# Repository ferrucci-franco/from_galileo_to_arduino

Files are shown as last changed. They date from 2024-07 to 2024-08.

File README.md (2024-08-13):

# From Galileo Galilei to Arduino
This page presents a low-budget (under USD 100) didactic tool for a simple pendulum with angle measurement and real-time plotting. 

The project involves measuring the angle of a pendulum and plotting the data in real-time using a incremental encoder, an Arduino UNO board and a computer running a graphical user interface, programmed in Python.

This tool, designed by [Franco FERRUCCI](mailto:franco.ferrucci@upf.pf) is part of the 'Introduction to Practical Work' sessions in the first year of the 'Engineering Science' bachelor's program at the University of French Polynesia.

You will find here all the necessary information to replicate this piece of equipment, such as the bill of material, the 3D models (for 3D printing), the code running in the Arduino board and the Python program that runs on the computer.

<p align="center">
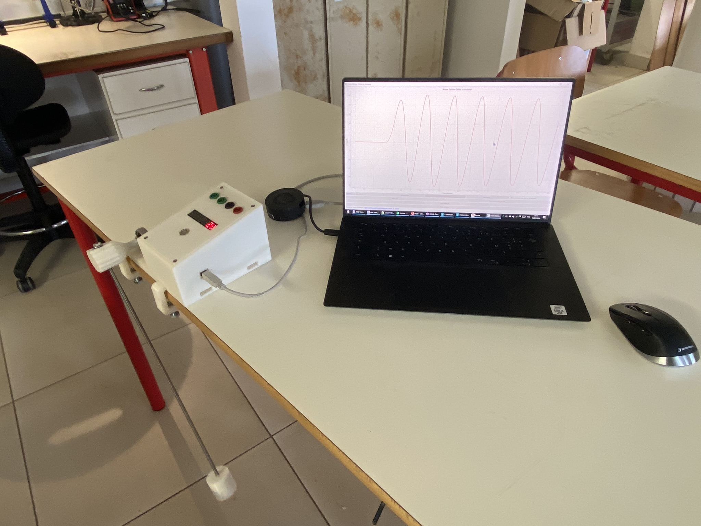
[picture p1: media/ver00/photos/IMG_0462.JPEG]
Intoductory photo
  
</p>

### How does it work?
The Arduino board reads signals from the incremental encoder, computes the pendulum angle, and displays it on a physical display. Simultaneously, it sends the data via a serial interface to a computer. A tool on the computer runs Python code that plots the pendulum angle in real time and allows the user to save the data to disk as a CSV file.

## Table of Contents
- [Repository recap](#repository-recap)
- [Videos](#videos)
- [Photos & Screenshots](#photos--screenshots)
  - [Photos](#photos)
  - [Real-Time Plot](#real-time-plot)
  - [Exported CSV file visualisation](#exported-csv-file-visualisation)
  - [Curve fitting](#curve-fitting)
- [Requirements](#requirements)
- [Python Code Installation](#python-code-installation)
- [Contribution](#contribution)
- [Contact](#contact)

## Repository recap
In this repository you will find the following elements:
- Arduino code
- Python code for:
  - The real-time graphical user interface (GUI)
  - An off-line data visualization tool of CSV measured data (using Plotly library).
  - A script with a curve-fitting tool for a sinusoidal curve with exponential decay.
  - A script with the numerical integration of the equations of motion of a physical pendulum and comparison with measurement (with an example!).
- CAD files and 3D printer files (I used Creality K1 printer). In a future commit I will upload the Fusion360 files.
- Pictures and screenshots.
- Bill of material (comming soon).
- Electrical diagram (comming soon).
## Videos
For an overview and demonstration of the project, you can watch the following videos:
- [Video 1 (YouTube)](https://youtu.be/FJ6ZPmrugeg?si=X3V44YTVULSpro3k)
- [Video 2 (YouTube)](https://youtube.com/shorts/YBjDby0IXsI?si=bWYj2W4k94o8iF31)
## Photos & Screenshots
Here are some photos and screenshots of the project in action:

### Photos
<p align="center">
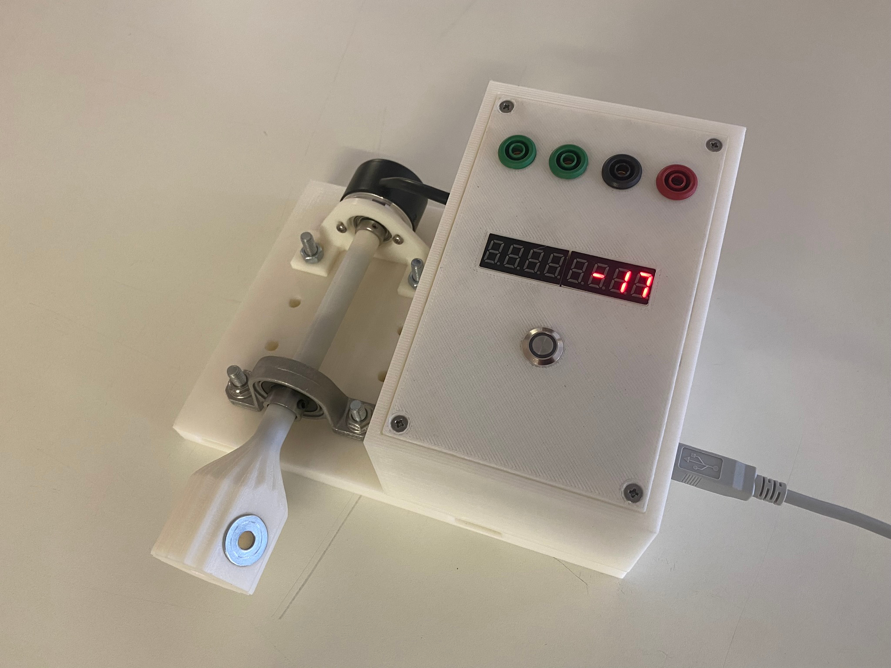
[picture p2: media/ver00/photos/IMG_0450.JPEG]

</p>
<p align="center">
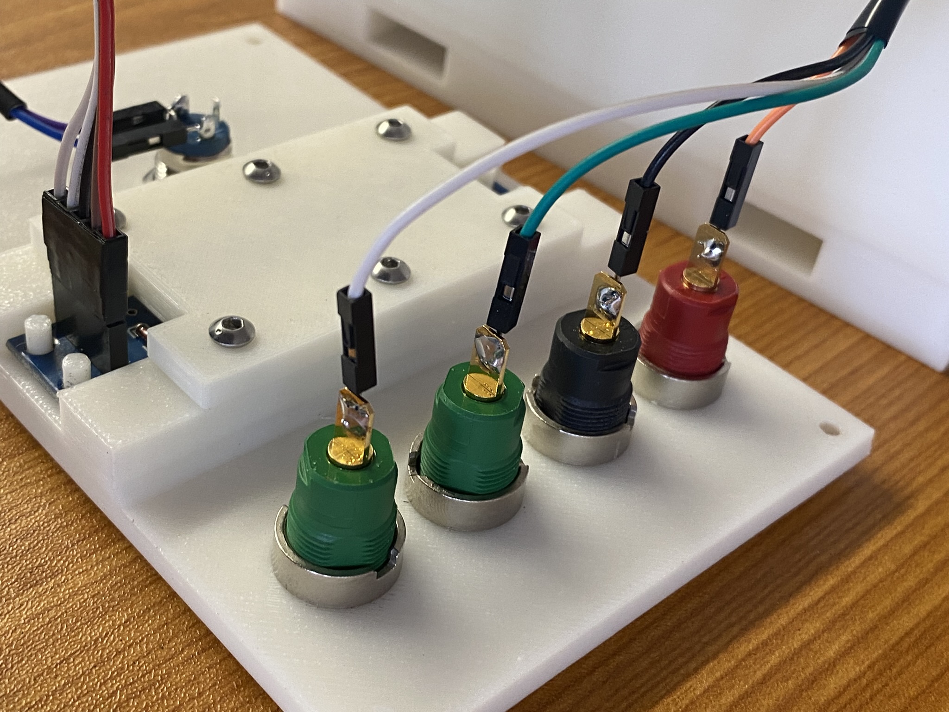
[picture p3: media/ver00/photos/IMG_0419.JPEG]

</p>
<p align="center">
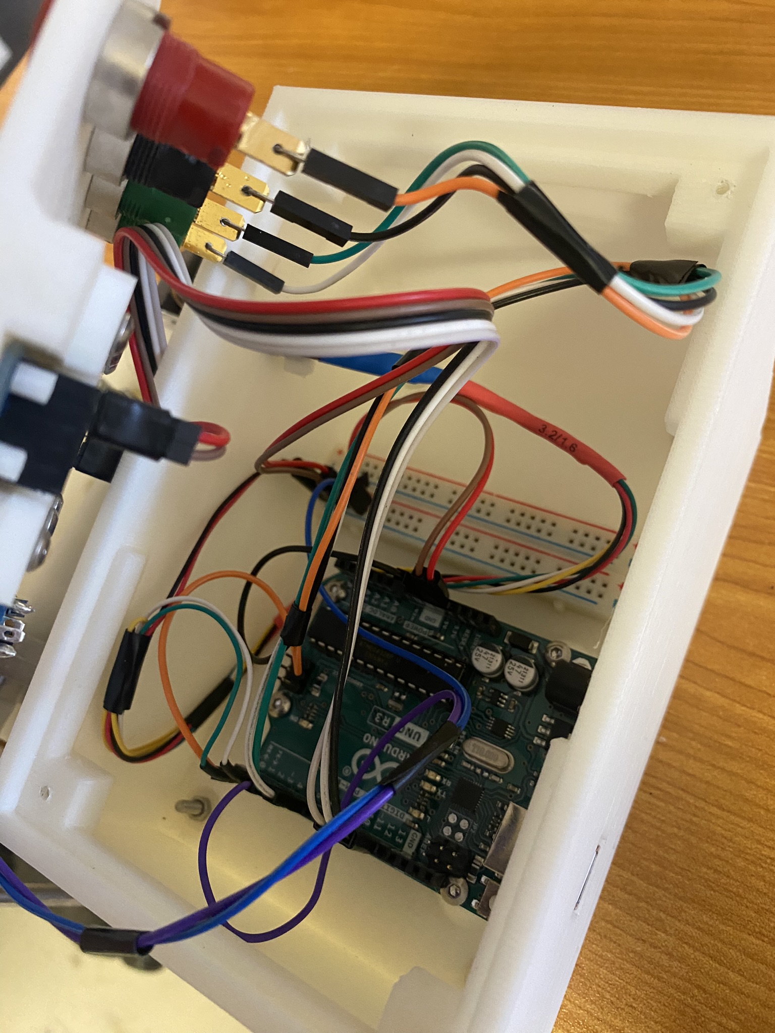
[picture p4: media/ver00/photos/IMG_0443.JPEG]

</p>

### Real-Time Plot
<p align="center">
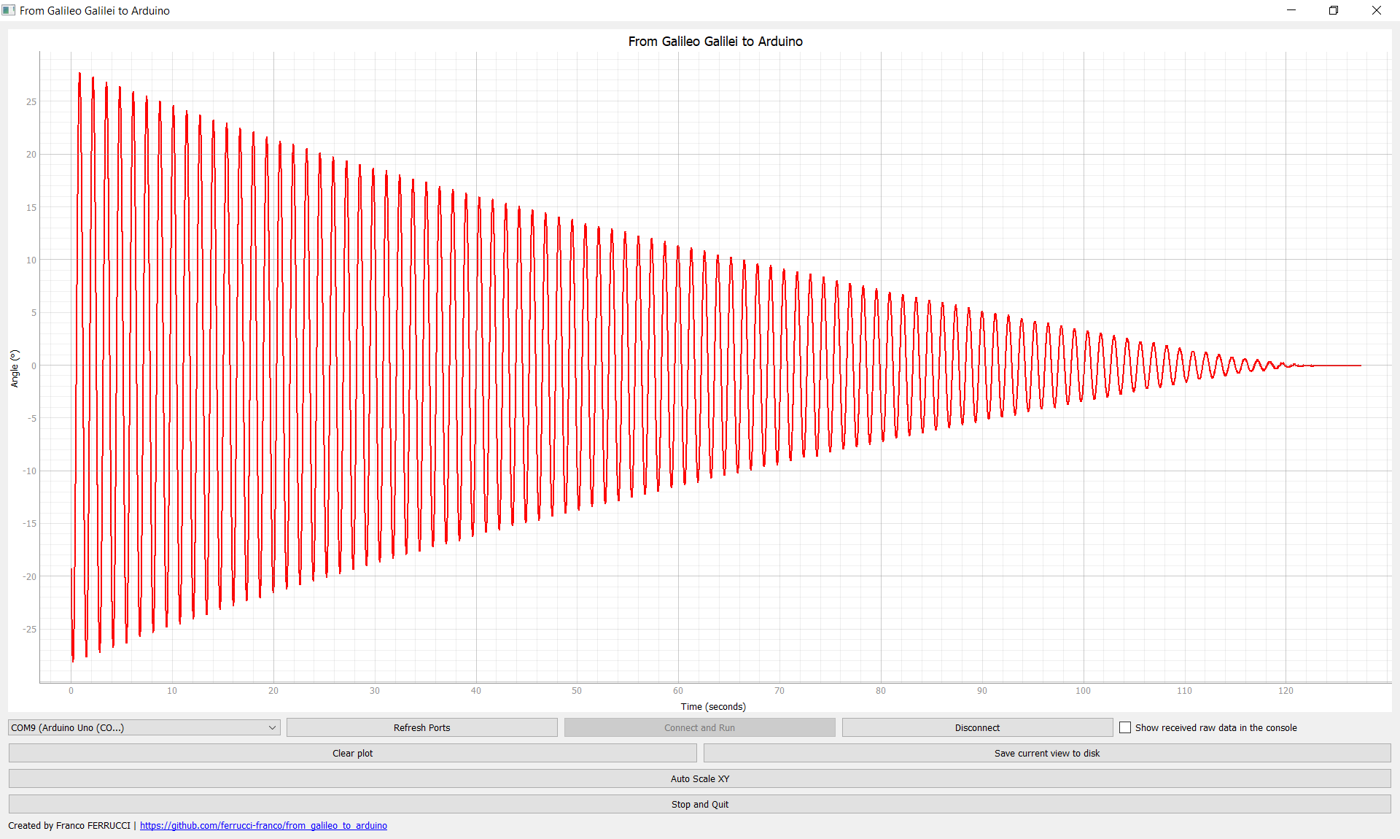
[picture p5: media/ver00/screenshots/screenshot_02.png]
Real-Time Plot

</p>

### Exported CSV file visualisation
<p align="center">
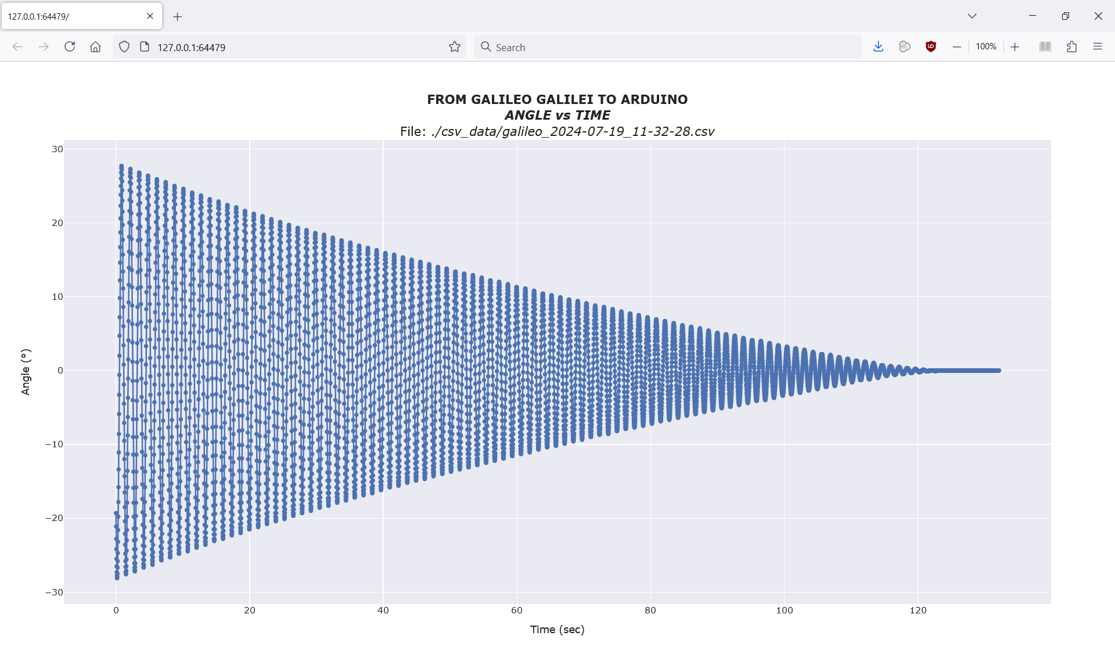
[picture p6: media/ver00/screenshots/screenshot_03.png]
Data Acquisition

</p>

### Curve fitting
<p align="center">
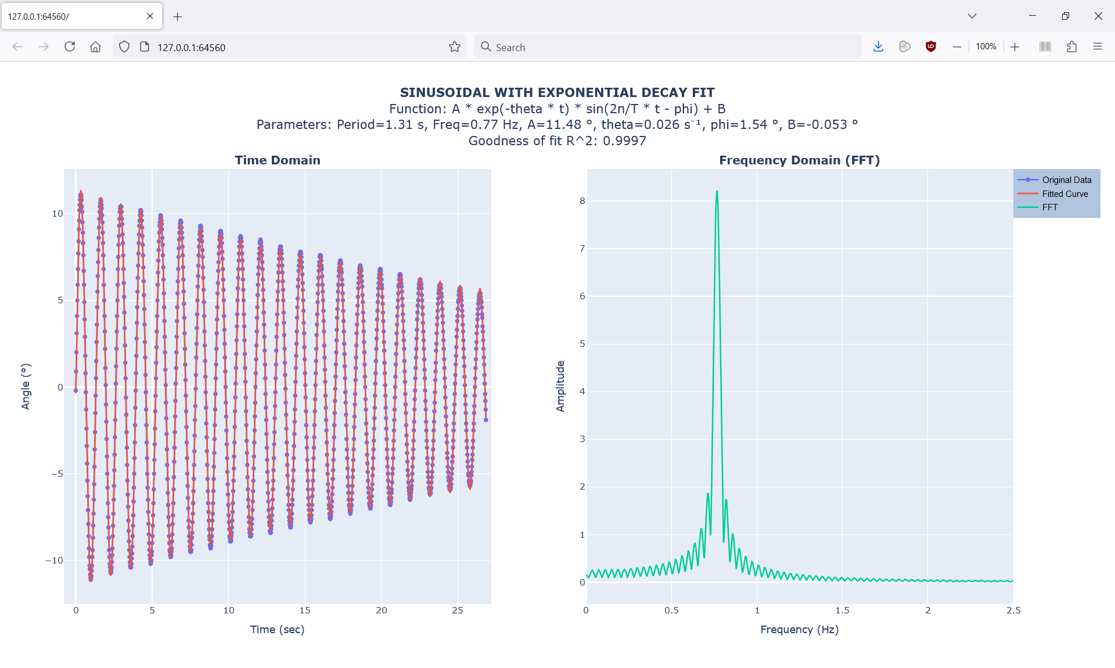
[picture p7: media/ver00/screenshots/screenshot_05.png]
Example Data Plot

</p>

## Requirements
- Arduino or compatible microcontroller
- Python 3.x
- Required Python libraries: `PyQt5`, `pyqtgraph`, `serial`, `pandas`, `plotly`

## Python Code Installation
To set up the necessary environment for running the provided Python code, follow the instructions below. This guide will walk you through creating an Anaconda environment called `galileo_to_arduino` and installing all the required libraries.
### Step 1: Install Anaconda
If you do not have Anaconda installed, you can download and install it from [the official Anaconda website](https://www.anaconda.com/products/distribution). If you don't have that much room in you hard drive, try Miniconda instead [(see link here)](https://docs.anaconda.com/miniconda/)
### Step 2: Create a New Environment
Open the Anaconda prompt and execute the following commands to create a new environment called `galileo_to_arduino`:
```
conda create --name galileo_to_arduino
```
### Step 3: Activate the Environment
Activate the newly created environment with the following command:
```
conda activate galileo_to_arduino
```
### Step 4: Install Required Libraries
Install the necessary libraries using the following commands:
```
conda install pyqt
conda install -c conda-forge pyqtgraph
conda install -c conda-forge pyserial
conda install pandas
conda install numpy
conda install scipy
conda install -c plotly plotly
```
### Step 5: Verify the Installation
To ensure all the libraries are installed correctly, you can run the following Python code:
```
import sys
import re
import os
from PyQt5.QtWidgets import QApplication, QMainWindow, QVBoxLayout, QHBoxLayout, QWidget, QPushButton, QComboBox, QCheckBox, QLabel
from PyQt5.QtCore import QTimer, QThread, pyqtSignal
import pyqtgraph as pg
import serial
import serial.tools.list_ports
import datetime
import pandas as pd
import numpy as np
from scipy.integrate import solve_ivp
import plotly.graph_objs as go
import plotly.io as pio
from scipy.optimize import curve_fit
import scipy.fftpack
from plotly.subplots import make_subplots
```
If no errors occur, the environment is set up correctly.
## Contribution
Feel free to contribute to this project by providing feedback, bug reports, or enhancements. You can also fork the repository and submit a pull request.
## Contact
For any questions or further information, please contact [Franco FERRUCCI](mailto:franco.ferrucci@upf.pf).

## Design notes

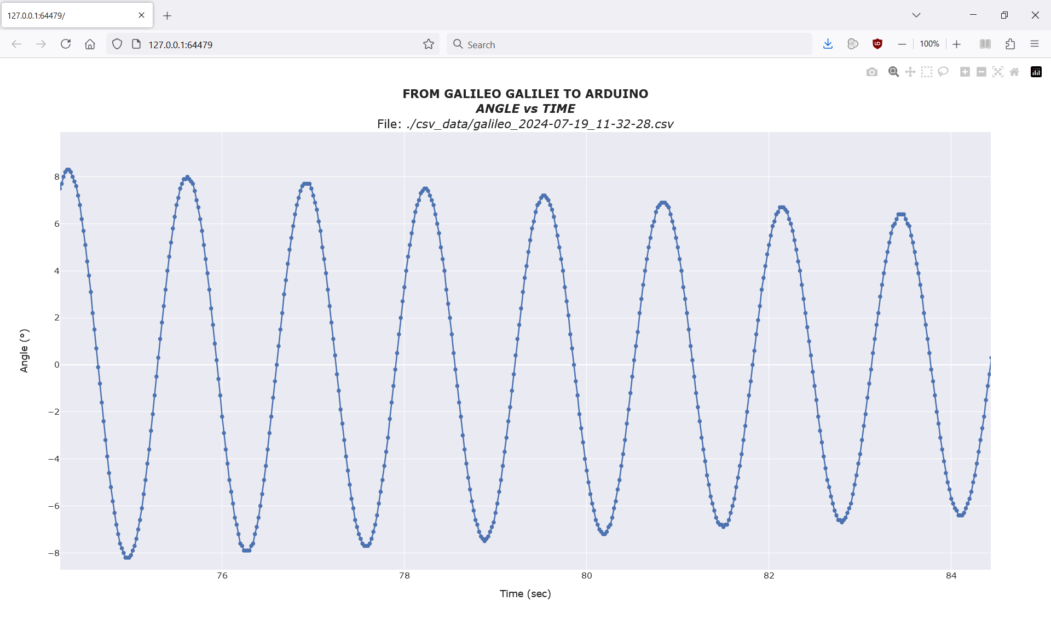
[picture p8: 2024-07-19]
media/ver00/screenshots/screenshot_04.png

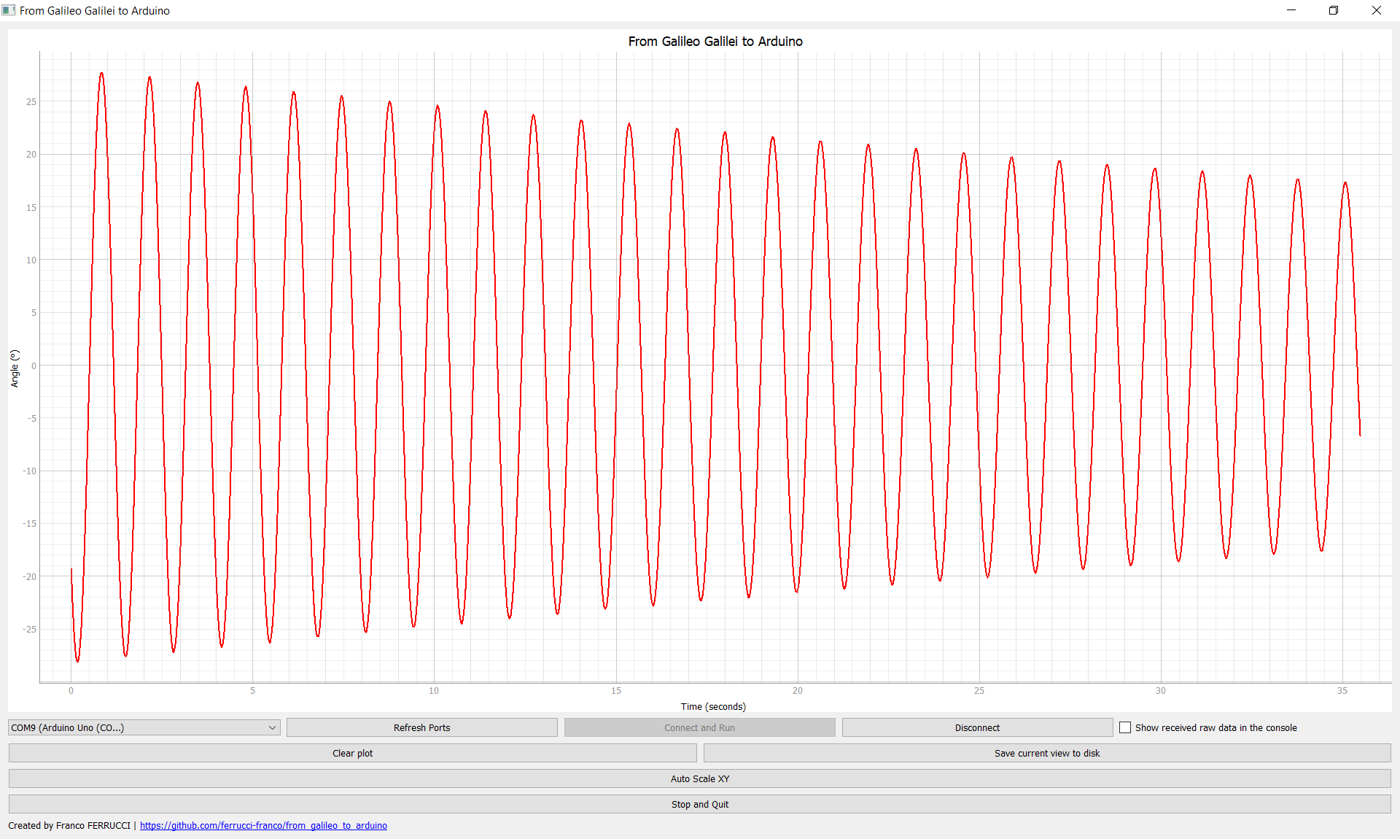
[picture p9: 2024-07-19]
media/ver00/screenshots/screenshot_01.png

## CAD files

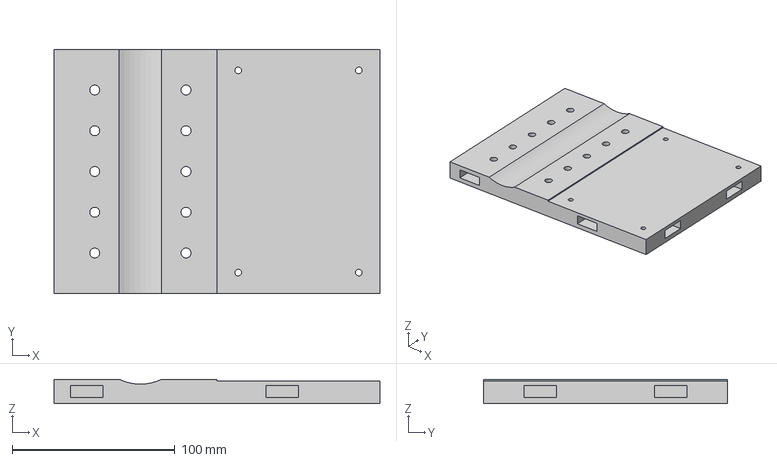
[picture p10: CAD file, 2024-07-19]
CAD/ver_00/base/base_01 v8.step
200.0 x 150.0 x 15.0 mm

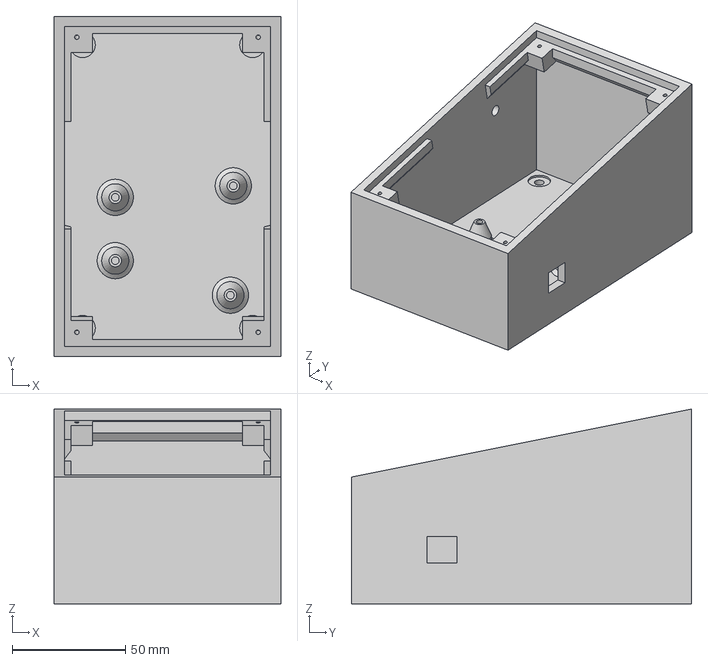
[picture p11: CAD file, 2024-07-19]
CAD/ver_00/box/base_01_box v46.step
100.0 x 150.0 x 86.0 mm

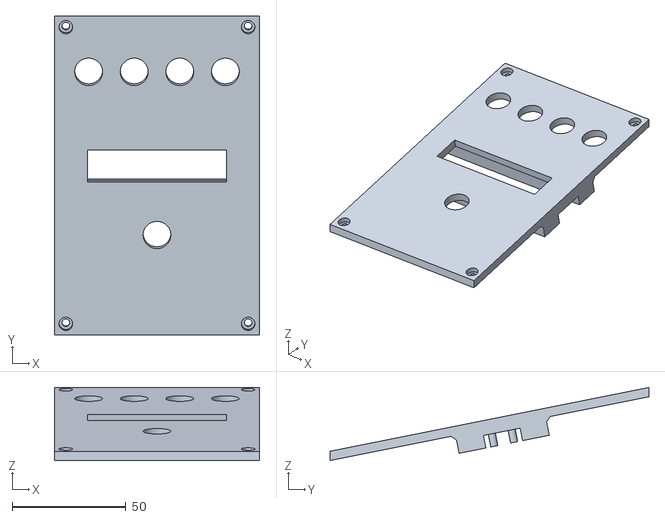
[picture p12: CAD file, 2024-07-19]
CAD/ver_00/box_cover/base_01_cover v39.stl
90.0 x 140.0 x 32.1

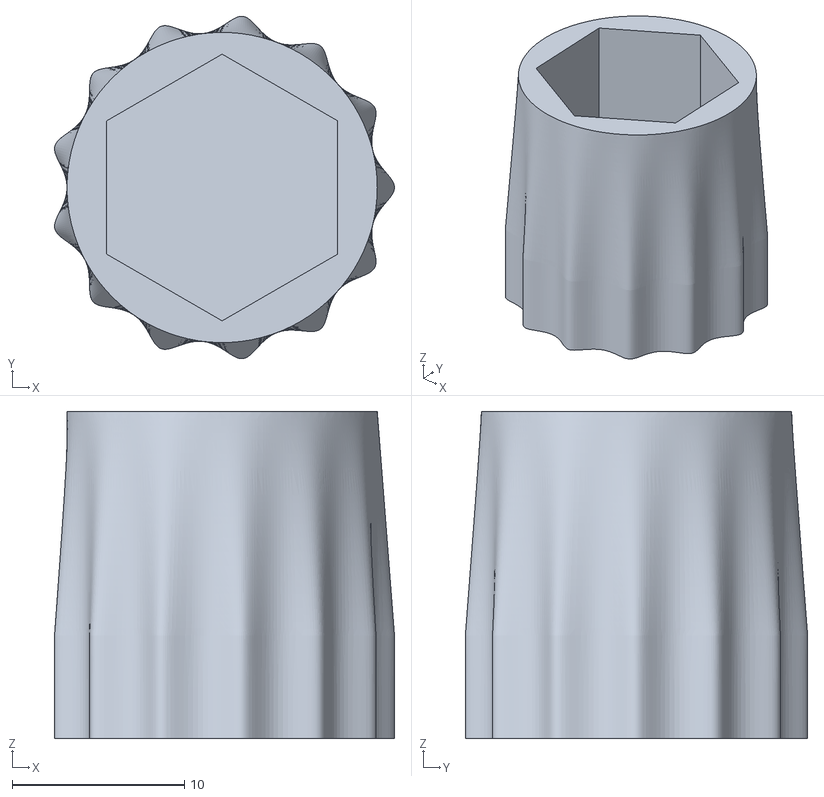
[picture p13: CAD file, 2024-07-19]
CAD/ver_00/clamps_handle/vice_handle_01 v3.stl
19.7 x 19.9 x 19.0

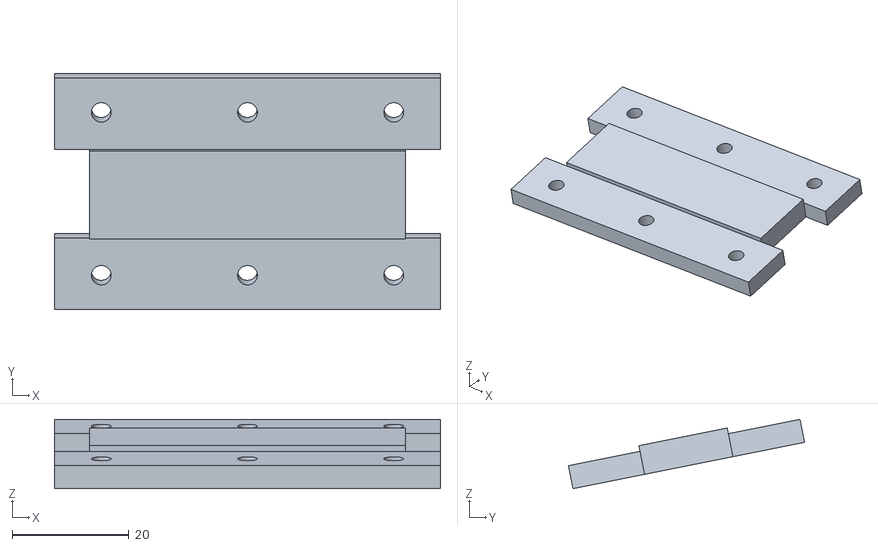
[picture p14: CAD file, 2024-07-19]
CAD/ver_00/display_support/base_01_display_support v43.stl
66.0 x 40.4 x 11.8

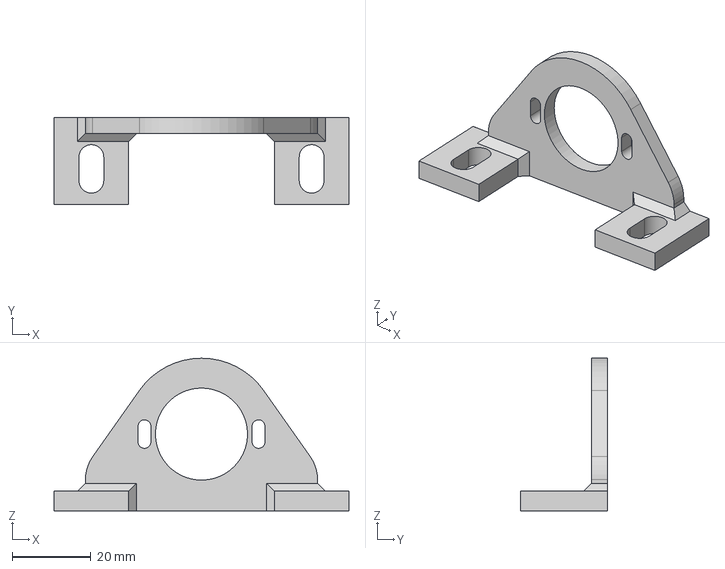
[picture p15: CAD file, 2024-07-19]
CAD/ver_00/encoder_holder/base_01 v15.step
75.0 x 22.0 x 38.8 mm

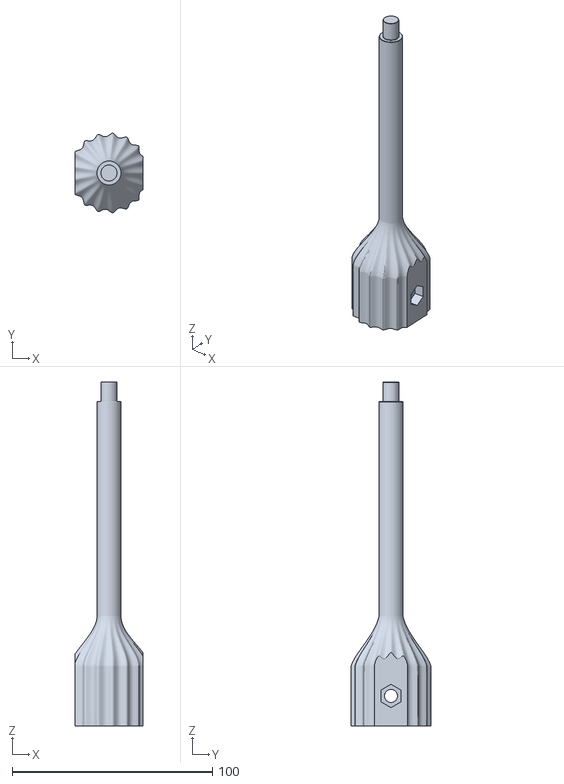
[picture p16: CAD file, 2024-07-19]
CAD/ver_00/shaft/shaft_02 v3.stl
34.0 x 39.8 x 171.8

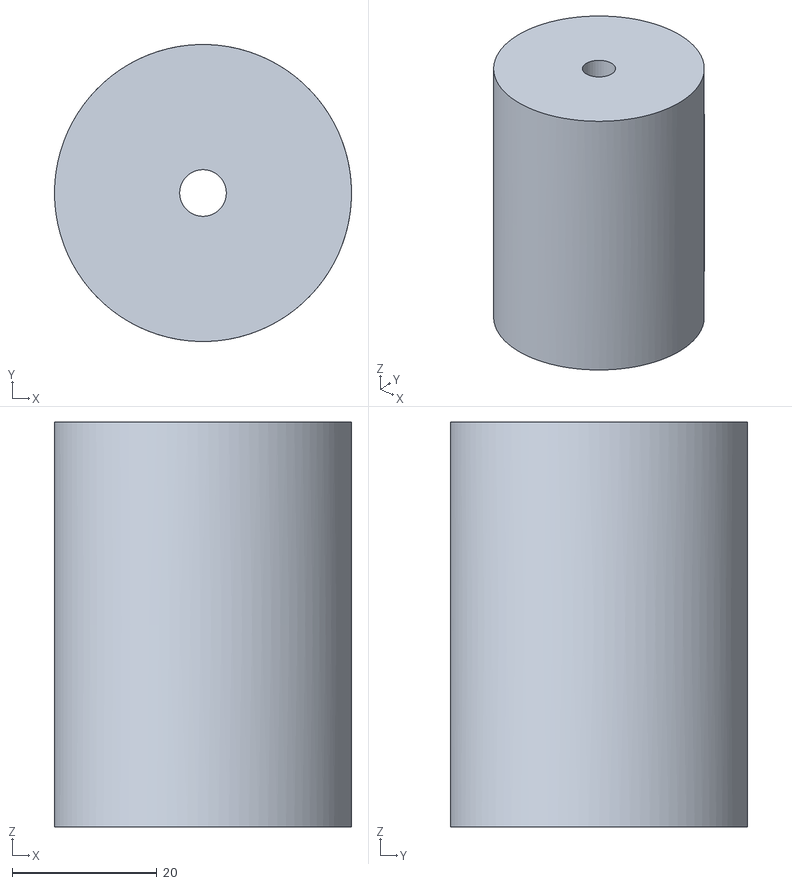
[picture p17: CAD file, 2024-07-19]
CAD/ver_00/weight_long/weight_03 v6.stl
41.0 x 41.0 x 55.9

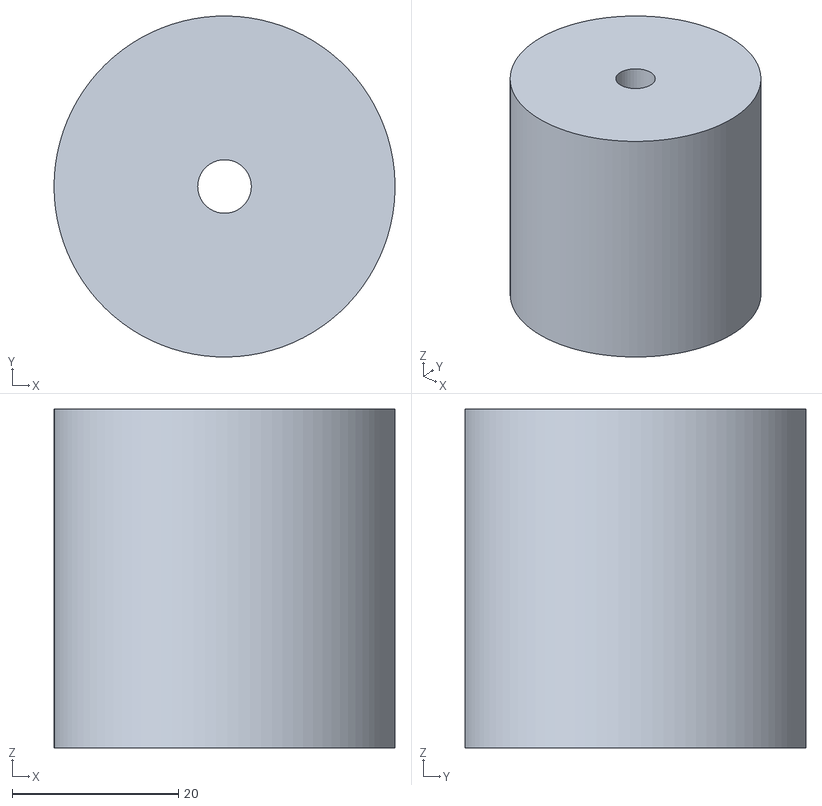
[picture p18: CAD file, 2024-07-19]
CAD/ver_00/weight_short/weight_04 v2.stl
41.0 x 41.0 x 40.7

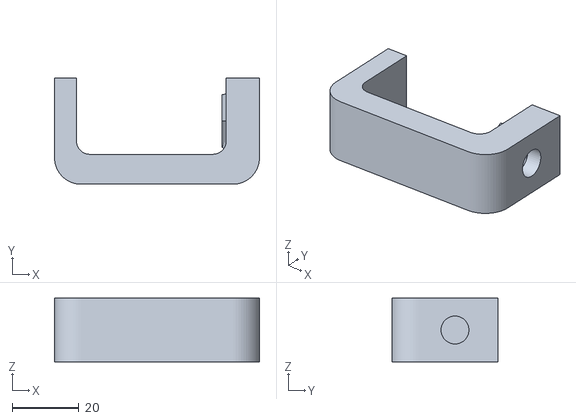
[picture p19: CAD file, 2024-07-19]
CAD/ver_00/clamps/vice_03 v3.stl
61.6 x 32.0 x 19.2

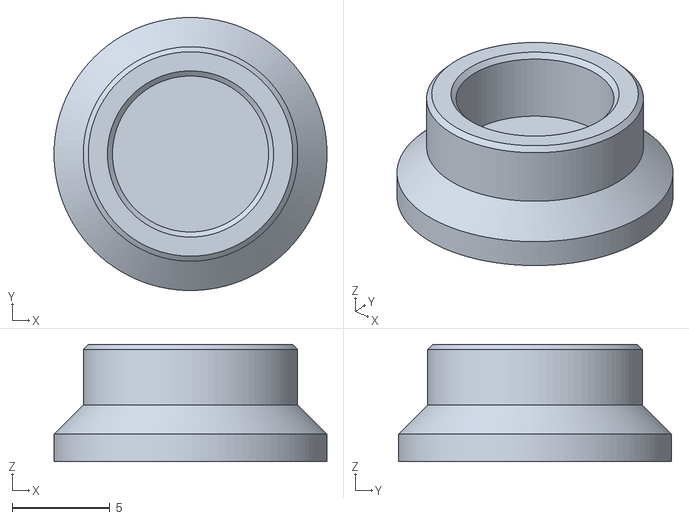
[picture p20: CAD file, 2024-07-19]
CAD/ver_00/clamps/vice_screw_end_01 v1.stl
14.0 x 14.0 x 6.00

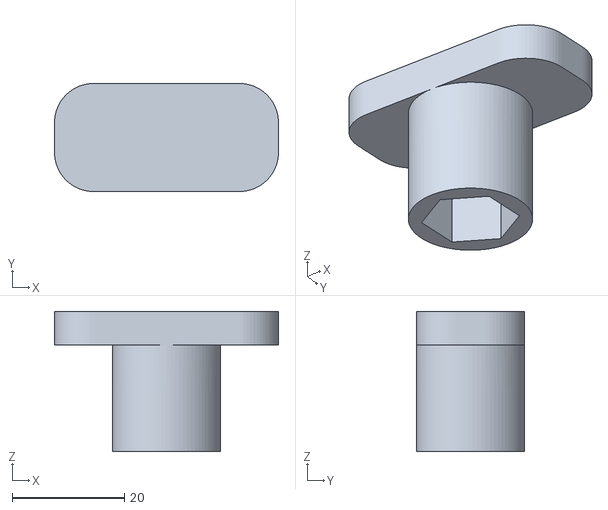
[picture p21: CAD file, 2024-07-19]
CAD/ver_00/nut_bolt_tube_tools/m8_tube_tool_01 v4.stl
40.0 x 19.3 x 25.0

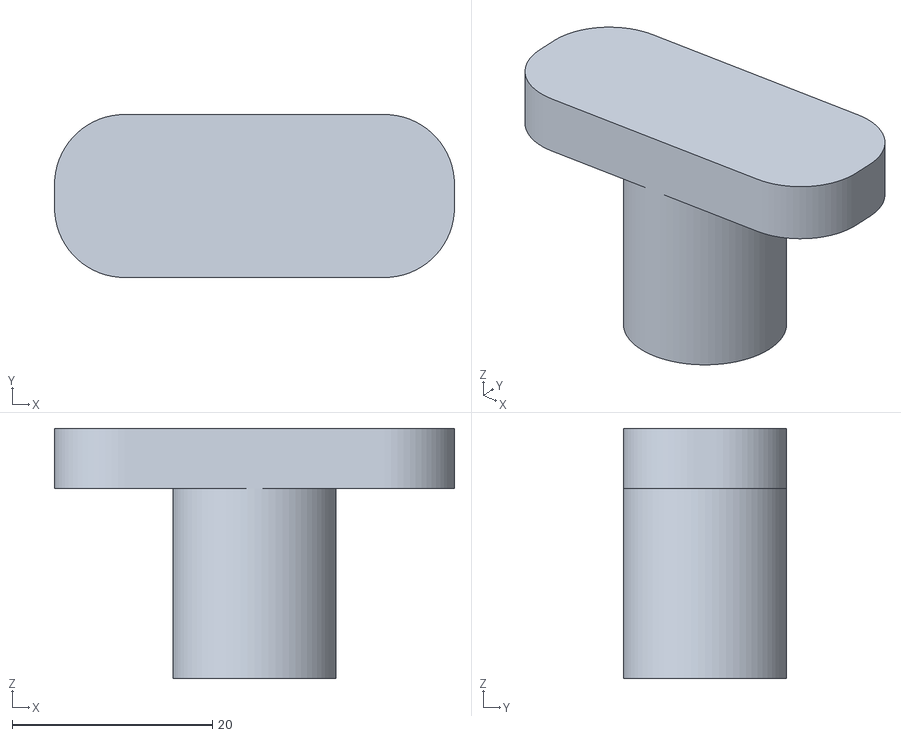
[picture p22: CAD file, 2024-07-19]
CAD/ver_00/nut_bolt_tube_tools/m6_tube_tool_01 v2.stl
40.0 x 16.3 x 25.0

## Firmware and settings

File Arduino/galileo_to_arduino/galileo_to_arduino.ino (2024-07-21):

/*
  From Galileo Galilei to Arduino.
  https://github.com/ferrucci-franco/from_galileo_to_arduino
  Author: Franco FERRUCCI
  
  Encoder Position and Angle Measurement

  This program measures the position and angle of a rotary encoder and displays the angle on a MAX7219 7-segment display. 
  It also provides options for serial communication and debugging using an LED.

  Libraries Used:
  - TimerOne: For setting up and handling Timer1 interrupt service routine.
  - digitalWriteFast: For faster reading and writing of digital pins.
  - max7219: For controlling the MAX7219 display.

  Debug Levels (_LOG_LEVEL_):
  0: No debug.
  1: Send raw 'encoderPosition' via serial port.
  2: Toggle a debug pin when timer enters ISR.

  Definitions:
  - BAUD_RATE: Serial communication baud rate.
  - TIMER1_MICROSECONDS: Timer1 interval in microseconds.
  - MAX7219 display control pins and brightness settings.

  Encoder Setup:
  - Pins for encoder channels A and B, and a button for resetting the encoder position.
  - Encoder constants for counts per revolution (CPR) and angle calculation.

  Timer Setup:
  - Timer1 for periodic interrupts to handle data sending and angle calculations.

  Functions:
  - setup(): Initializes serial communication, pin modes, interrupts, Timer1, and the MAX7219 display.
  - loop(): Main loop to check button state and send data to the serial port and display.
  - updateEncoder(): Interrupt service routine to update encoder position based on pin changes.
  - sendData(): Timer1 interrupt service routine to increment time counter, calculate angle, and set flag for data transmission.
  - displayAngle(float angle): Converts the angle to a string and displays it on the MAX7219.

  Usage:
  - Connect the encoder to the specified pins and initialize the system by uploading the code.
  - The angle will be displayed on the MAX7219 display, and data can be sent to the serial port based on the debug level.
*/

#include <TimerOne.h>           // Timer1 library (interrupt service routine).
#include <digitalWriteFast.h>   // Library that reads and write pins faster.
#include <max7219.h>            // Library to control MAX7219 display.

#define _LOG_LEVEL_ 0 // 0: No debug.
                      // 1: Send raw 'encoderPosition' via serial port.
                      // 2: Toggle debug pin 1 when timer enter ISR.

// Serial transmission baud rate:
#define BAUD_RATE (115200)

// Timer 1 defines:
#define TIMER1_MICROSECONDS (20000)
#define TIMER1_MILLISECONDS (TIMER1_MICROSECONDS/1000)

// MAX7219 display defines:
#define LEFT  0
#define RIGHT 1
#define MAX7219_NUMBER_OF_DECIMALS 0

// MAX7219 library, redefine REG_INTENSITY. Note: 0x01 = low intensity, 0x0A = high intensity:
#ifdef REG_INTENSITY
#undef REG_INTENSITY
#define REG_INTENSITY     0x08                       
#endif

// MAX7219 library, redefine MAX_CLK pin (in case we want to change pin number):
#ifdef MAX_CLK
#undef MAX_CLK
#define MAX_CLK 10                       
#endif

// MAX7219 library, redefine MAX_CS pin (in case we want to change pin number):
#ifdef MAX_CS
#undef MAX_CS
#define MAX_CS 11                       
#endif

// MAX7219 library, redefine MAX_DIN pin (in case we want to change pin number):
#ifdef MAX_DIN
#undef MAX_DIN
#define MAX_DIN 12                       
#endif

// Define the pins for the encoder and the button:
const int encoderPinA = 2; // Interrupt pin 0
const int encoderPinB = 3; // Interrupt pin 1
const int buttonPin = 4;   // Button pin
const int encoderPinA_out = 5; // pin to duplicate 'encoderPinA' input 
const int encoderPinB_out = 6; // pin to duplicate 'encoderPinB' input

// Encoder variables:
volatile long encoderPosition = 0;
volatile double angle = 0;
volatile bool lastA = LOW;
volatile bool lastB = LOW;
volatile bool there_is_something_to_send = LOW;

// Encoder constants:
const double encoder_CPR = 1000.0; // CPR: counts per revolution
const double encoder_divisor = encoder_CPR * 4.0 / 360.0; // 4 pulses per count, as in any incremental encoder

// Timer counter:
volatile unsigned long timeCounter = 0;

// Debug pin:
#if (_LOG_LEVEL_ == 2)
const int debugPin1 = 7;
#endif

// Declares display struct:
MAX7219 max7219;

void setup() {
  Serial.begin(BAUD_RATE);

  // Set the encoder pins as inputs
  pinModeFast(encoderPinA, INPUT);
  pinModeFast(encoderPinB, INPUT);

  // Set encoder output pins (equal to input pins)
  pinModeFast(encoderPinA_out, OUTPUT);
  pinModeFast(encoderPinB_out, OUTPUT);

  // Enable pull-up resistors for encoder
  digitalWriteFast(encoderPinA, HIGH);
  digitalWriteFast(encoderPinB, HIGH);

  // Set the button pin as input with pull-up resistor
  pinModeFast(buttonPin, INPUT_PULLUP);

  // Debug pin
  #if (_LOG_LEVEL_ == 2)
  pinModeFast(debugPin1, OUTPUT);
  digitalWriteFast(debugPin1, LOW);
  #endif

  // Attach interrupts to the encoder pins
  attachInterrupt(digitalPinToInterrupt(encoderPinA), updateEncoder, CHANGE);
  attachInterrupt(digitalPinToInterrupt(encoderPinB), updateEncoder, CHANGE);

  // Initialize Timer1 for periodic interrupt
  Timer1.initialize(TIMER1_MICROSECONDS);   // Set timer to TIMER1_MICROSECONDS micro-seconds
  Timer1.attachInterrupt(sendData);         // Attach the function to the timer interrupt

  // Initialize display
  max7219.Begin();
  max7219.MAX7219_SetBrightness(REG_INTENSITY);

}

void loop() {
  // Read the button state
  bool buttonState = digitalReadFast(buttonPin);

  if (buttonState == LOW) {
    encoderPosition = 0;
  }

  if (there_is_something_to_send == HIGH) {
    // Print the time mark and angle to the serial port:
    Serial.print("Time: ");
    Serial.print(timeCounter * TIMER1_MILLISECONDS); // Time in milliseconds
    Serial.print(" ms, Angle: ");
    Serial.println(angle, 1); // Angle with one decimal point

    // Display the angle on the MAX7219:
    displayAngle(angle);

    // Turn off flag:
    there_is_something_to_send = LOW;
  }
}

void updateEncoder() {
  // Read the encoder pins:
  bool newA = digitalReadFast(encoderPinA);
  bool newB = digitalReadFast(encoderPinB);

  // Compute encoder direction and add or substract accondingly:
  if (newA != lastA || newB != lastB) {
    if (newA == lastB) {
      encoderPosition++;
    } else if (newB == lastA) {
      encoderPosition--;
    }
  }
  // Store these values for next time:
  lastA = newA;
  lastB = newB;

  // Replicate pins to output:
  digitalWriteFast(encoderPinA_out, newA);
  digitalWriteFast(encoderPinB_out, newB);
}

void sendData() {
  // Increment the time counter:
  timeCounter++;

  // Calculate the angle:
  angle = encoderPosition / encoder_divisor;

  // Update flag to transmit data over serial port:
  there_is_something_to_send = HIGH;

  // Send raw encoder position:
  #if (_LOG_LEVEL_ == 1)
  Serial.println(encoderPosition >> 2);
  #endif

  // Toggle debug pin:
  #if (_LOG_LEVEL_ == 2)
  digitalToggleFast(debugPin1);
  #endif
}

void displayAngle(float angle) {
  // Convert float to string with 'MAX7219_NUMBER_OF_DECIMALS' decimal places:
  char buffer[9];
  dtostrf(angle, 8, MAX7219_NUMBER_OF_DECIMALS, buffer);

  // Write on display:
  max7219.DisplayText(buffer, RIGHT);
}

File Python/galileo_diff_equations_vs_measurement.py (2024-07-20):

# -*- coding: utf-8 -*-
"""
Created on Thu Jul 11 08:01:57 2024
@author: Franco FERRUCCI

This script simulates the motion of a pendulum using differential equations 
and compares the simulation results with experimental data from a CSV file. 
It solves the equations of motion for a "physical" pendulum with given 
friction, mass, moment of inertia and the length of the rod, and then plots
the simulated angular displacement against the angular displacement from 
the CSV file. 

The plot shows the simulation and measurement data, allowing for visual 
comparison of the theoretical model with real-world measurements.

For information about the equation of motion of a "simple" pendulum vs 
a "physical" pendulim, see:
https://phys.libretexts.org/Bookshelves/University_Physics/University_Physics_I_-_Classical_Mechanics_(Gea-Banacloche)/11%3A_Simple_Harmonic_Motion/11.03%3A_Pendulum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

"""

import pandas as pd
import numpy as np
from scipy.integrate import solve_ivp
import plotly.graph_objs as go
import plotly.io as pio

# Global variables:
truncate_csv_time = True
csv_filename = './csv_data/galileo_2024-07-19_15-25-54.csv'

# Constants
b = 0.00125         # Friction coefficient
M = 0.11544         # Mass
L = 0.687           # Length of the rod
d = L / 2           # Distance of the center of mass of the rod to the rod extreme
J = M * L**2 / 3    # Moment of inertia
g = 9.81            # Gravitational acceleration

# Natural frequency for small angles
omega_natural_small_angles = np.sqrt(3 * g / (2 * L))
T_natural_small_angles = 2 * np.pi / omega_natural_small_angles

# Initial conditions
theta_0 = np.deg2rad(-68.6)  # Initial angle in radians
omega_0 = 0.5  # Initial angular velocity

# Time span for simulation
t_span = (0, 60)  # 0 to 60 seconds
t_eval = np.linspace(t_span[0], t_span[1], 2000)  # Time points where the solution is evaluated

# Differential equations
def equations(t, y):
    theta, omega = y
    dtheta_dt = omega
    domega_dt = -(b * omega + M * g * d * np.sin(theta)) / J
    return [dtheta_dt, domega_dt]

# Solve the differential equations
sol = solve_ivp(equations, t_span, [theta_0, omega_0], t_eval=t_eval)

# Extract the results
t_sim = sol.t
theta_sim = np.rad2deg(sol.y[0])  # Convert the simulation results to degrees

# Read the CSV file
data = pd.read_csv(csv_filename)

# Extract time and angle from CSV
t_csv = data['Time'].values
theta_csv = data['Angle'].values  # Angle is already in degrees

# Truncate CSV data to match the simulation time span
if truncate_csv_time:
    mask = (t_csv >= t_span[0]) & (t_csv <= t_span[1])
    t_csv = t_csv[mask]
    theta_csv = theta_csv[mask]

# Plot the results using Plotly
fig = go.Figure()

# Add simulation result
fig.add_trace(go.Scatter(x=t_sim, y=theta_sim, mode='lines', name='Simulation',
                         line=dict(width=5)))  # Increase the width of the blue curve

# Add CSV data
fig.add_trace(go.Scatter(x=t_csv, y=theta_csv, mode='lines+markers', name='Measurement', marker=dict(size=5)))

title =  f'<b>FROM GALILEO GALILEI TO ARDUINO</b><br>'
title += f'<b>Pendulum Simulation vs CSV Data</b><br>'
title += f'File: '
title += '<i>' + str(csv_filename) + '</i>'

fig.update_layout(
    title=title,
    xaxis_title='Time (s)',
    yaxis_title='Theta (deg)',
    showlegend=True,
    template='plotly'
    # template='seaborn'
    # template='plotly_dark'
    # template='plotly_white'
)

# Render the plot
pio.renderers.default = 'browser'
fig.show()

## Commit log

2024-07-19 Create galileo_to_arduino.ino
    Arduino project file. First commit.
2024-07-19 Python files, first commit.
    Python files (including the user interface program). First commit.
    [galileo_2024-07-19_09-27-13.csv]
2024-07-19 CAD files, ver 00
    CAD files, initial commit. Note: parts printed with Creality K1 printer.
    [base_01 v15.step, base_01 v8.step, base_01_box v46.step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]
2024-07-20 Add file that solve equation of motion and compares it with measurement.
    [galileo_2024-07-19_15-25-54.csv]
